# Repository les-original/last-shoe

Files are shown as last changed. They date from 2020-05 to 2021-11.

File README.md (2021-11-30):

# Last Shoe - The first bike shoe from LES ORIGINAL

### About 

#### FREE YOUR CLEATS FROM TYRANNY!
Performance cycling footwear in the comfort of your own home.

#### YOU DO SHOE.
The world's first additive-enabled bike shoes. Last is an open, modular and serviceable bike shoe platform made to adapt to any season, terrain or adventure.

#### RIGIDITY & FLEXION?
Designed for biking and hiking. The shoe is made to suit commuters, tourists and bikepackers who use the shoe for walking and biking. It's a firm pedaling platform with Metatarsal Articulation for walkability.

This project is a continuation of the _**N+ Platform**_, a project started by Marcs Wilkinson as a capstone project in **Product Design** at the _Wilson School of Design_, Kwantlen Polytechnic University.

**This model fits European size 45**

It's an additive enabled bike shoe designed to end all bike shoes. Designed for the creative cyclists, the project aspires to provide a shoe that is:

- Serviceable
- Modular
- Customizable

### Get Started & Stay Informed
[Les Original signup](https://www.marcsist.com/things/les-original/)

### See our other products
[Notion site](https://www.notion.so/lesoriginal/Products-c73553a3f9564c49b675799e58984206)


<br />This work is licensed under a <a rel="license" href="http://creativecommons.org/licenses/by-sa/4.0/">Creative Commons Attribution-ShareAlike 4.0 International License</a>.

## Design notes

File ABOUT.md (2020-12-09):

# Last bike shoe

## Challenges

1. Build adaptable bikepacking footwear with variable stiffness outsoles for riding and hiking
2. Most adventure cyclists ride through variety of climate and terrain, and buying purpose specific shoes adds up
3. With composite shanks, hardware and foams, cycling shoes are a multi-material disposal disaster

## Outcomes

1. A pleated rigid core that stops just shy of the metatarsal. Testing showed walkability close to a trail runner, while maintaining pedal stiffness comparable to a mountain bike shoe.
2. The N+ Platform - a quiver-killer of a shoe design that adapts to different types of riding, weather and adventures.
3. World's first additive-enabled, open source cycling shoe. Modular, serviceable, repairable with an open source design riders can adapt to their own needs. Semi-circular 3D printed TPU soles can be recycled into feedstock for new soles.

---

N+ is a bicycle shoe designed to provide a stiff pedaling platform while maintaining walkability off the bike. It's also an open-source design that's modular, serviceable and can be produced with readily available tools and techniques. It's a project exploring new consumer models of ownership and challenging expectations around the product life cycle.

N+ Platform was the final project of my Bachelor of Design - Product Design program in 2016 - read the  [Thesis Report](https://www.notion.so/Thesis-Report-795fb820494c4eefa807762894f369b8)

## Research

For this research project I was focused (okay not strictly focused as you will see...) on variable stiffness outsoles. The paradox I set out to solve — a walking/hiking shoe isn't ideal for biking, and a bike shoe is notoriously clumsy to walk in.

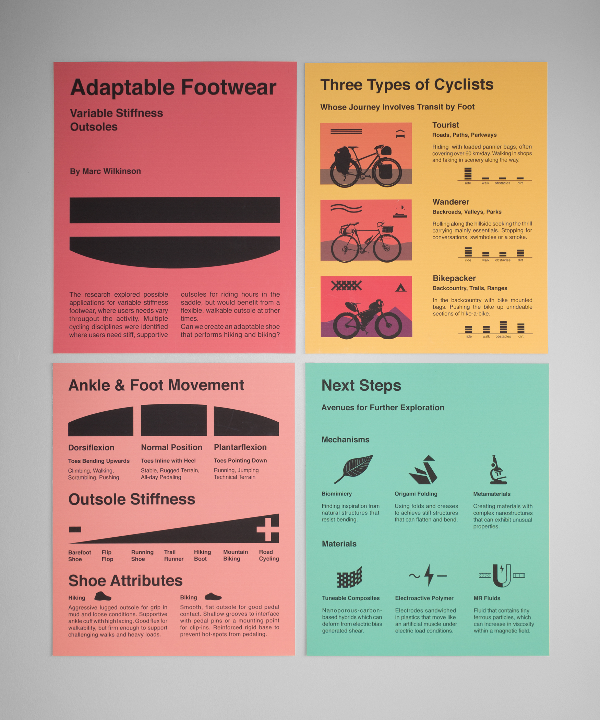
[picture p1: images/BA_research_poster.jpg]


Early research posters identifying challenge & opportunities



A mix of sketches at various fidelity

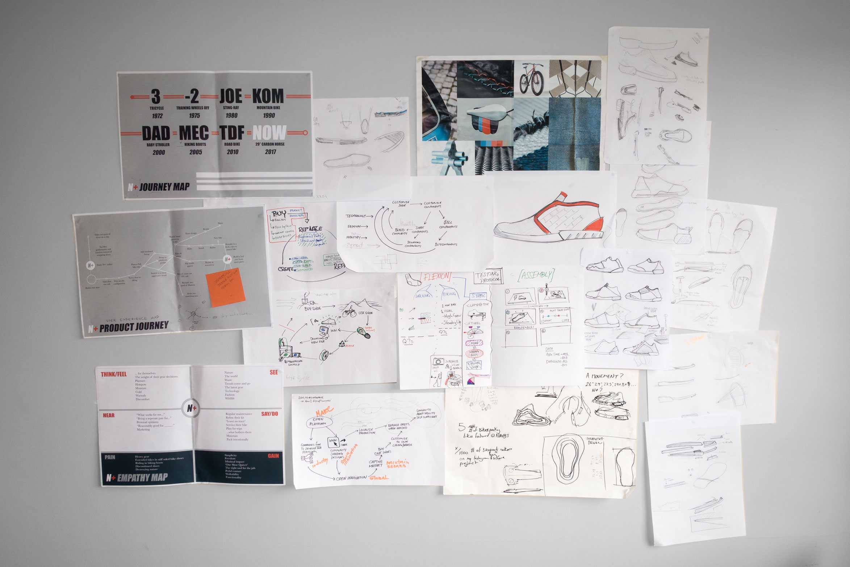
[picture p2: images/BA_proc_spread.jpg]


Assorted artefacts arranged on a wall

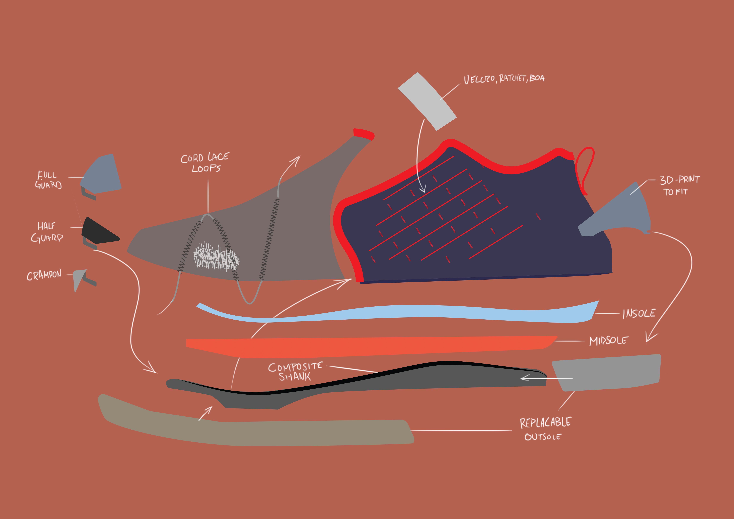
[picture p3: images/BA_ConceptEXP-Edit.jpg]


Exploded view of a concept (illustrator)

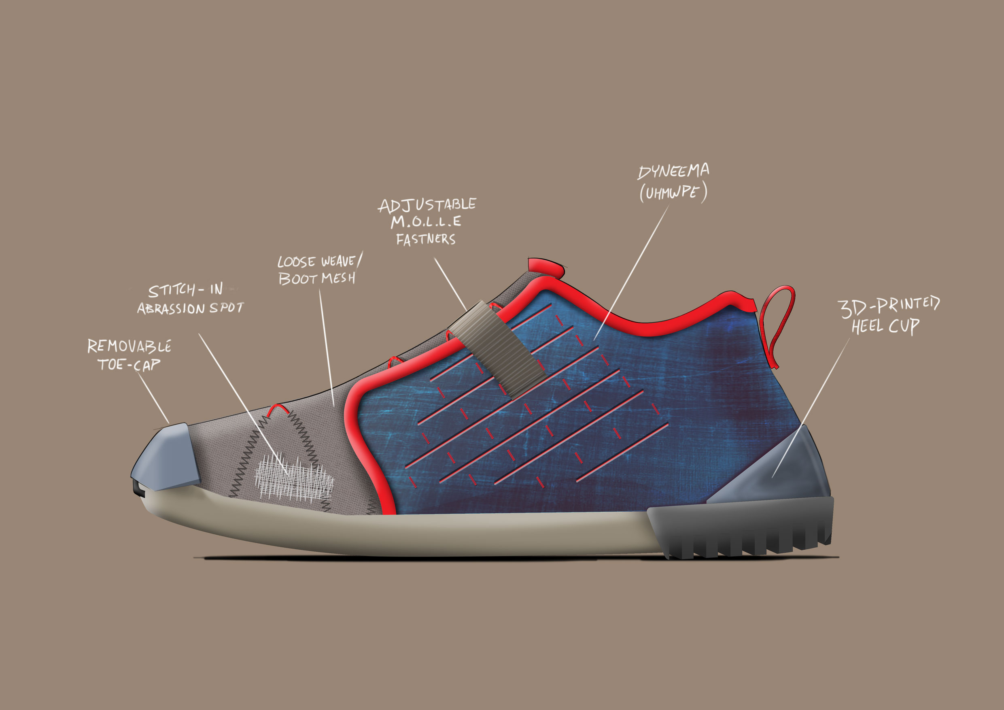
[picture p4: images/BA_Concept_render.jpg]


Rendered concept (photoshop)

## Design

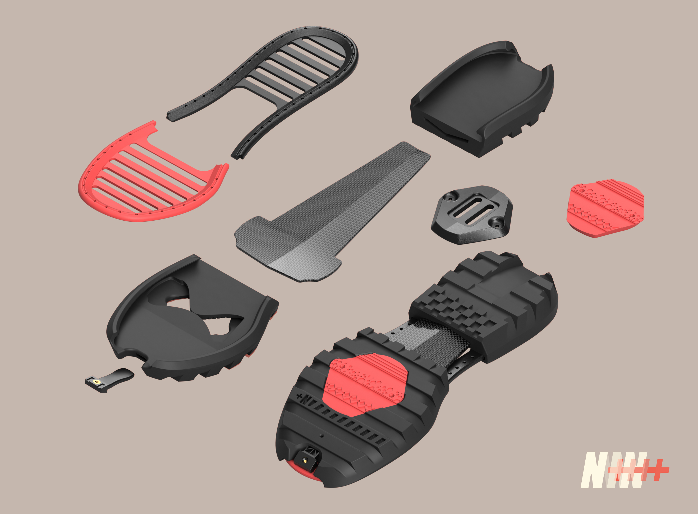
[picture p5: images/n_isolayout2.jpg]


Render in Fusion360 - one assembly surrounded by disassembled counterpart

### Modular Design

The shoe is designed as a modular system that allows riders to tweak and tune the shoe in the same way they would get a bike 'dialed' for a particular adventure.

- Easy to repair and disassemble
- replaceable outsole made without glue
- repairable and interchangeable textile
- tunable for different conditions, seasons, rides

As a bonus, non-traditional construction makes for a more sustainable extended product lifecycle. High-wear pieces like the outsole can be replaced when they're worn, and at different rates too — pedal wear happening faster than walking/heel wear. Textiles that tear or stink can be washed, repaired or replaced. The composite core, which will last centuries, fits a range of sizes and can be reused forever - leave it in your will!

### Additive-Enabled

Exploring the potential of digital manufacturing, I've used the term 'additive-enabled' because the composite core us made using a 3D printed mold and 3D printed threaded inserts to give shape to the core. The textile uppers are produced with good old fashioned textile technologies.

The frame (heel & toe), outsole (heel & toe), pedal inserts (platform & SPD) and toe-guard were all 3D printed.

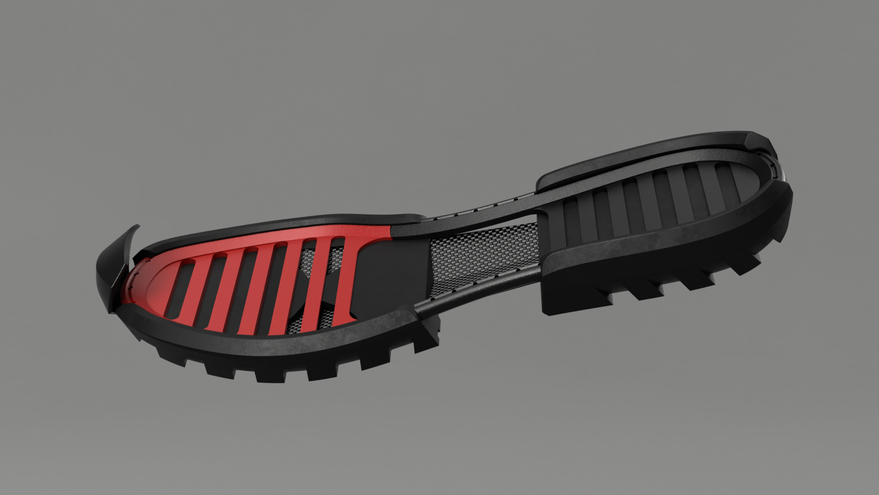
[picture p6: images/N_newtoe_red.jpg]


Render shown without textile uppers



Close-up of 3D printed TPU outsole

### Open-source Platform

So why a platform? What does that even mean? This project wouldn't have happened if it weren't for the RepRap project and proliferation of affordable 3D printing. I released the designs and project with an open source license because it would allow for a few interesting possibilities;

- People creating and sharing patterns and designs and components for free or profit
    - It would allow space for cottage makers to produce textile uppers, an interesting challenge and SKU
- Collaboration & competition
    - Imagine tire manufacturers adapt their existing tire tread catalog to fit the shoes
    - Imagine composite companies producing and selling cores
    - Imagine clothing and accessory brands can step into the shoe market with textile uppers and other parts
- Make nice bike shoes more accessible
    - People can make do with what they have available to hack together a decent shoe for themselves, that idea is pretty unthinkable for performance cycling shoes.
    - Eventually a market of used components (carbon cores) could exist to be combined with new replacement parts (fresh treads, textile uppers)

---

[les-original/last-shoe](https://github.com/les-original/last-shoe)



Assembled shoe, shoe components, DIY kit option

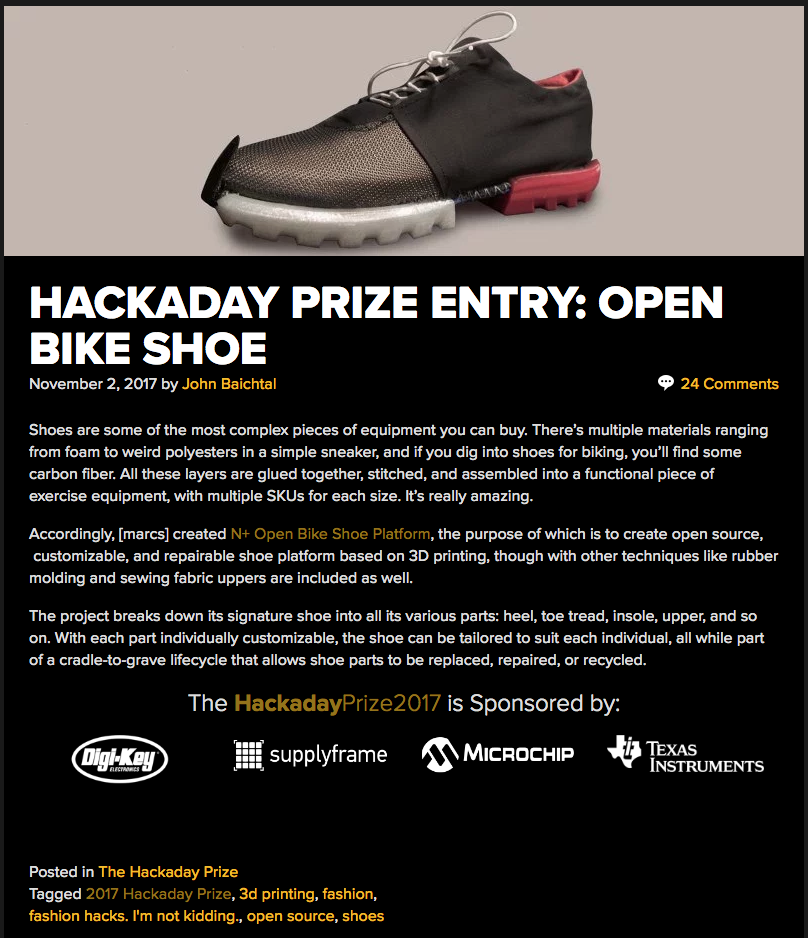
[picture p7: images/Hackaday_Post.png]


Top 20 finalist for **Hackaday**Prize2017 'Anything Goes' category

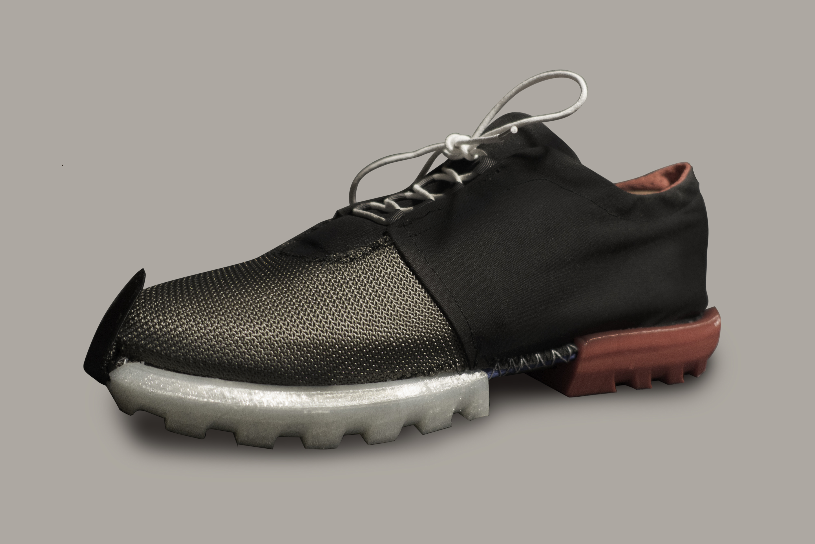
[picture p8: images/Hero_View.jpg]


Assembled shoe

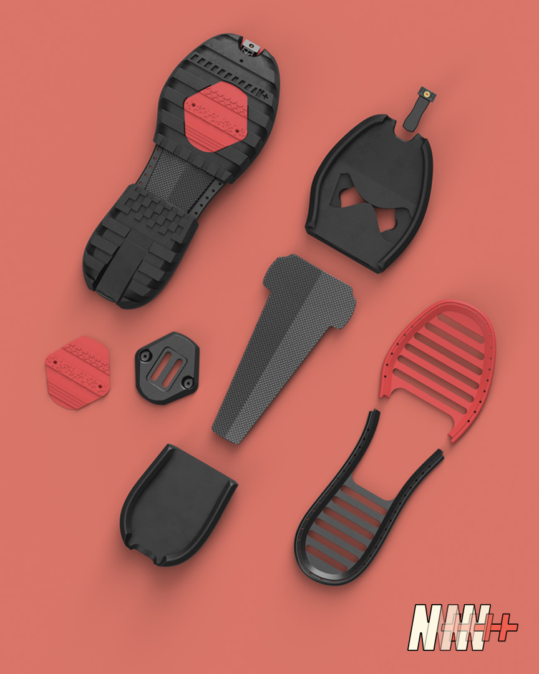
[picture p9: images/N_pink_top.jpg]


### Construction

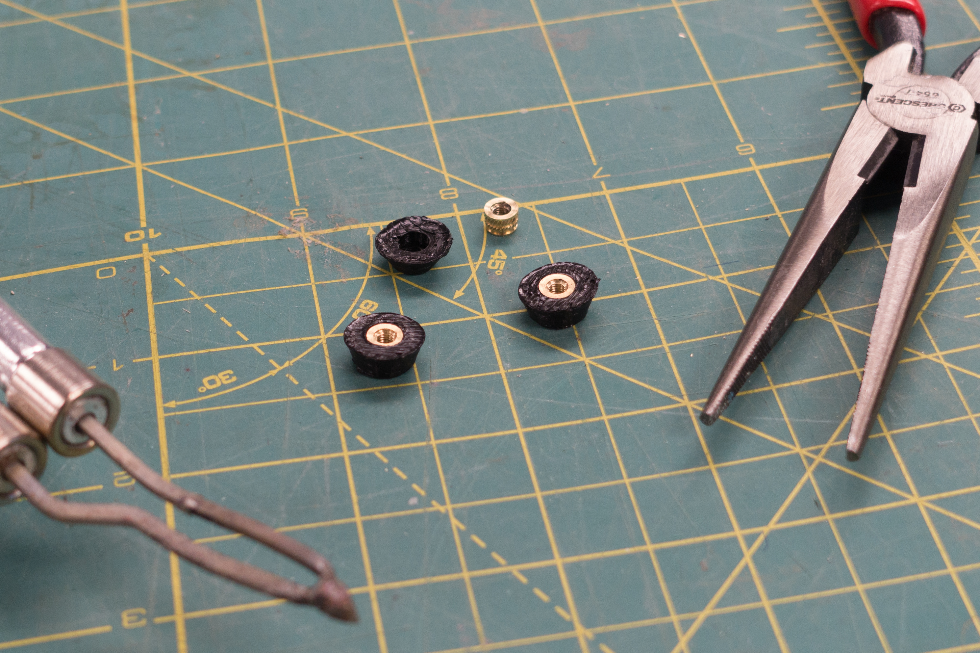
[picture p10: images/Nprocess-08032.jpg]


3D printed core inserts with heat-set threads



3D printed heel frame



Composite lay-up of the core

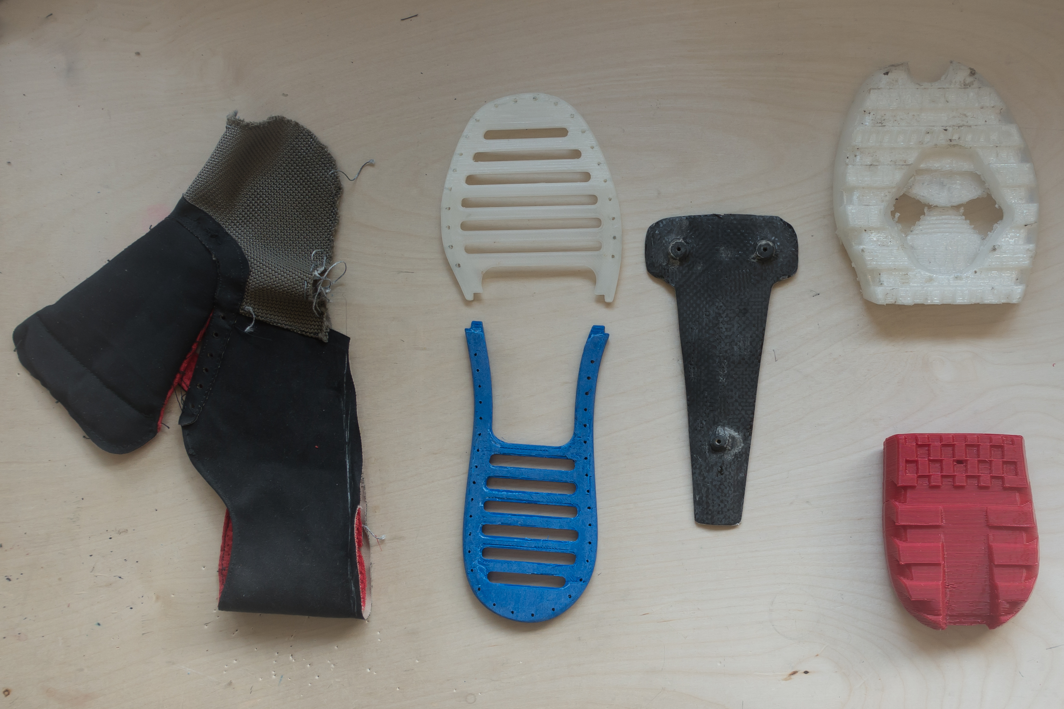
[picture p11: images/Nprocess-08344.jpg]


Textile uppers, frame, core, outsole



Printed mold, inserts, and CF/Flax matrix in a FoodSaver vacuum bag



Assembled after testing - with platform pedal insert

### Testing



Toe flexion - walking

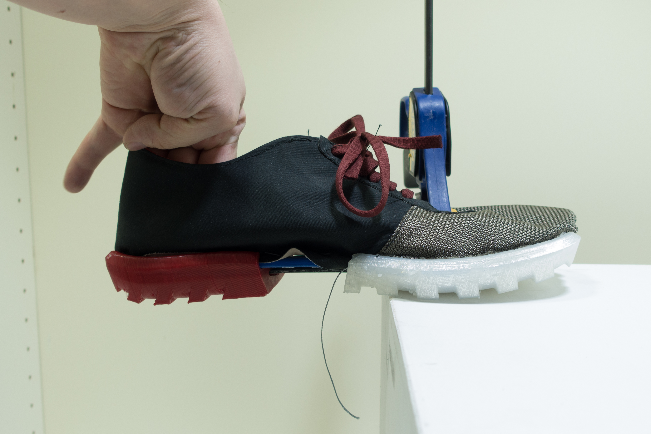
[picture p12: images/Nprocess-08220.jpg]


Toe flexion - pedalling

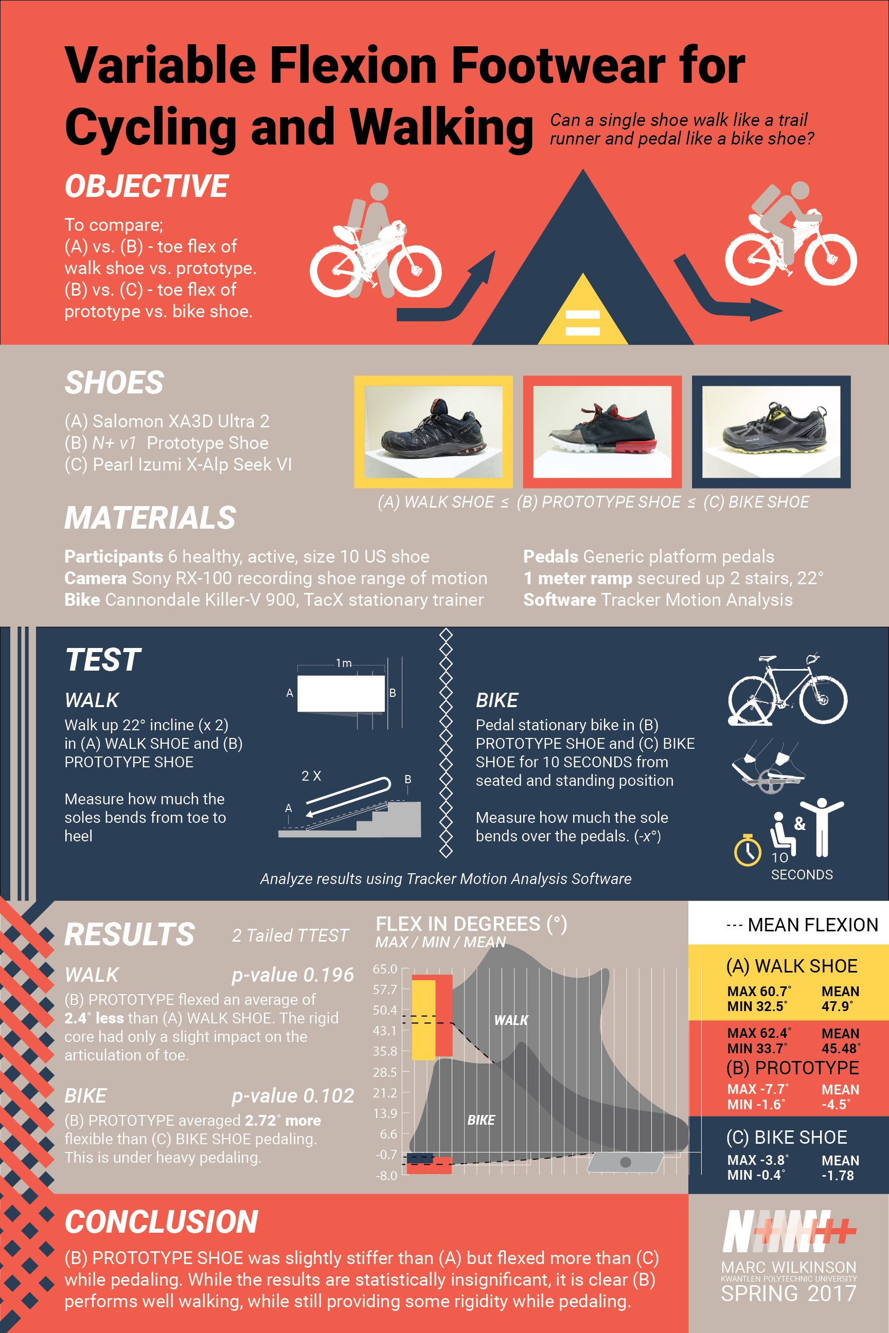
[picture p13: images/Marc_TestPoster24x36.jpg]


Research Testing Poster

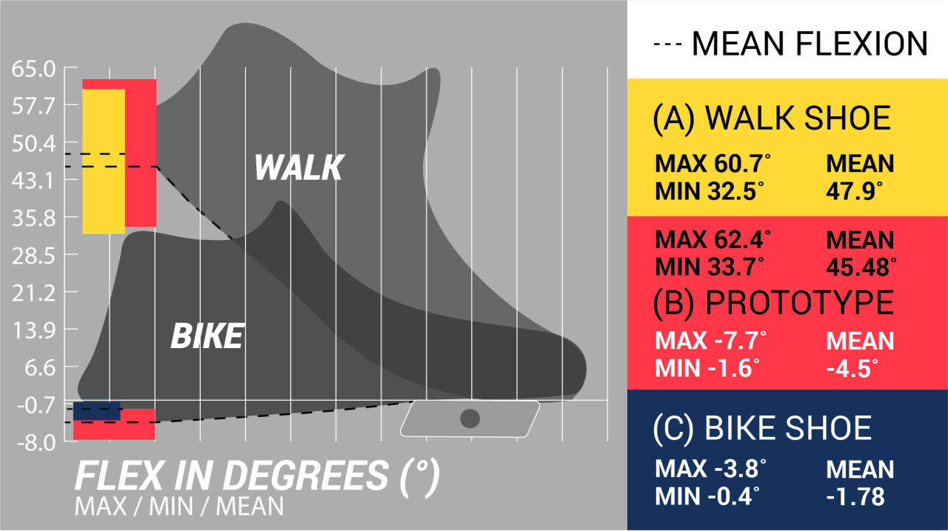
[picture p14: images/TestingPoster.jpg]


Testing Results show the prototype performed comparably to a cycling shoe and a trail runner



Three comparison shoes

# More Links

**I've shared some stuff on Instagram**

[#nplusplatform](https://www.instagram.com/explore/tags/nplusplatform/)

[@nplus.bike](https://www.instagram.com/nplus.bike/)

[Sign up](https://last.lesoriginal.com/n-plus-signup) to access more stuff related to this project

[GitHub repo](https://github.com/les-original/last-shoe)

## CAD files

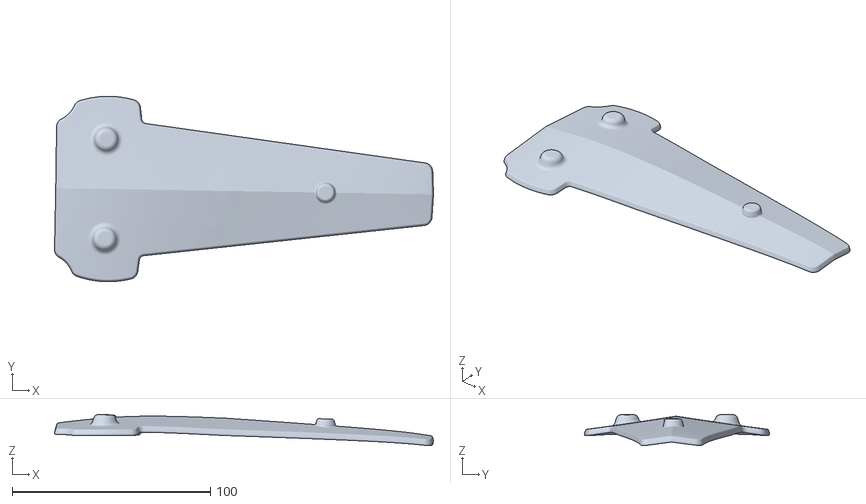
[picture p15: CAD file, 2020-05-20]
CORE/STL/last_core.stl
191.0 x 93.4 x 15.7

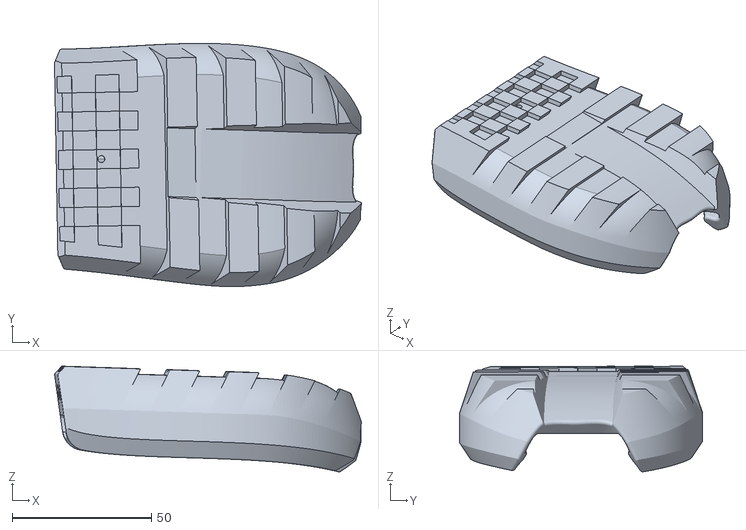
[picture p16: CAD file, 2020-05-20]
OUTSOLE/STL/Last_heel_US10.stl
110.2 x 87.3 x 38.0

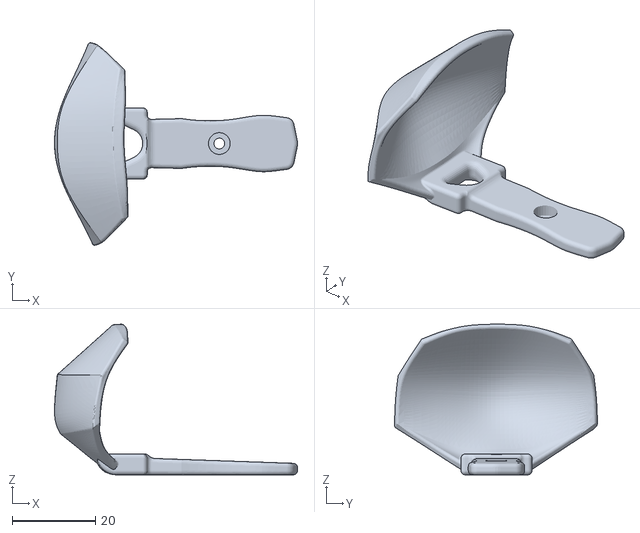
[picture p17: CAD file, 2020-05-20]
TOE GUARD/STL/Last_toeguard_v2.stl
58.5 x 48.7 x 36.2

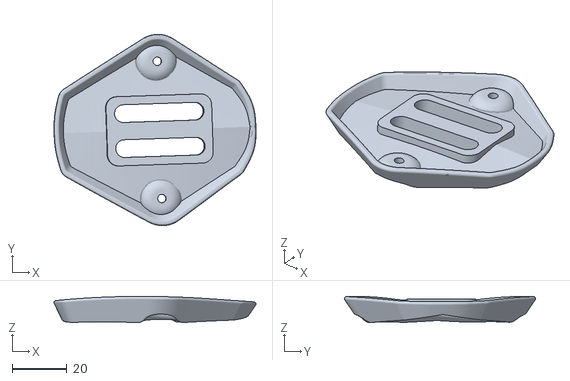
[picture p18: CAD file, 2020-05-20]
OUTSOLE/STL/Last_SPDinsert_US10.stl
73.5 x 69.7 x 9.56

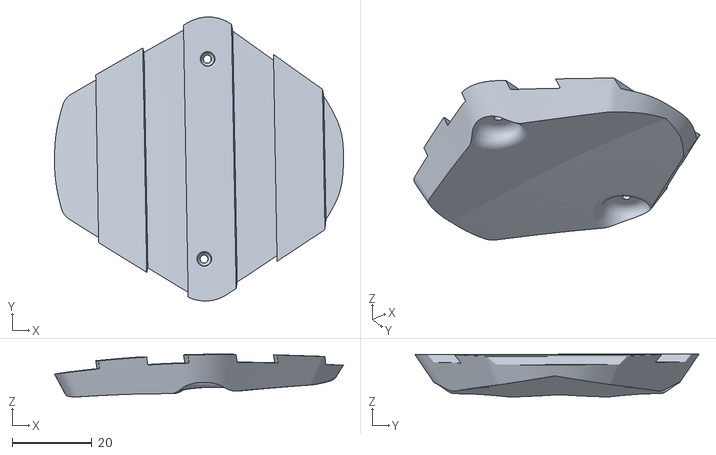
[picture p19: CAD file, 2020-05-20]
OUTSOLE/STL/Last_toeinsert_US10.stl
72.3 x 71.0 x 10.7

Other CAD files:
CORE/last_core.f3d
FRAME/Last_frame_toe_EU45.f3d
OUTSOLE/Last_SPDinsert_EU45.f3d
OUTSOLE/Last_toeinsert_EU45.f3d
TOE GUARD/Last_ToeGuard.f3d
TOE GUARD/Last_Toeguard Insert.f3d

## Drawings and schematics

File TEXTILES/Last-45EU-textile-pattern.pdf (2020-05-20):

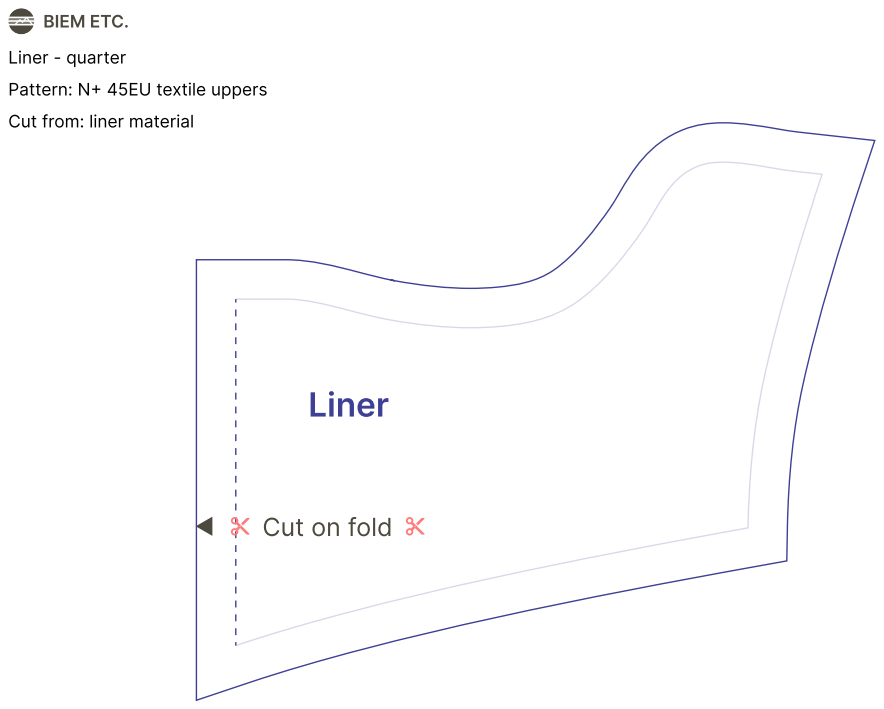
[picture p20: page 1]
Liner; BIEM ETC.; Liner - quarter

Pattern: N+ 45EU textile uppers

Cut from: liner material

Cut on fold

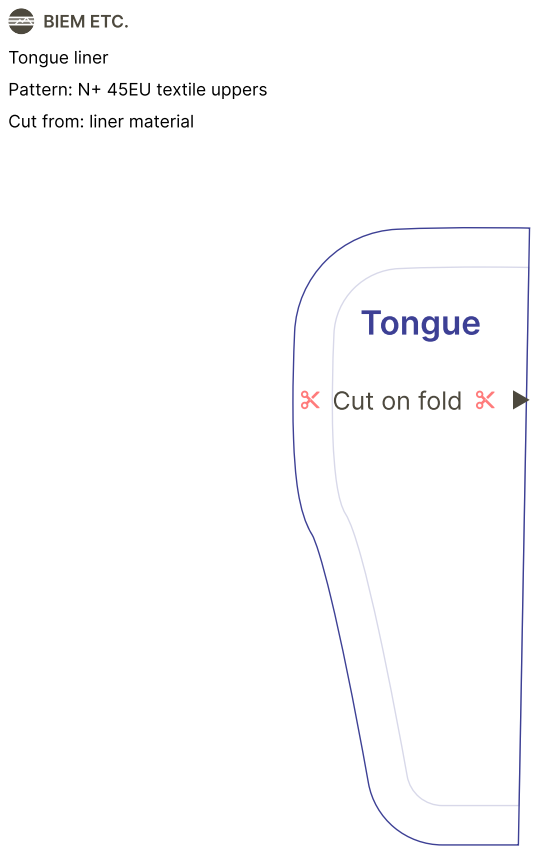
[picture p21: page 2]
Tongue; Tongue liner

Pattern: N+ 45EU textile uppers

Cut from: liner material

Cut on fold

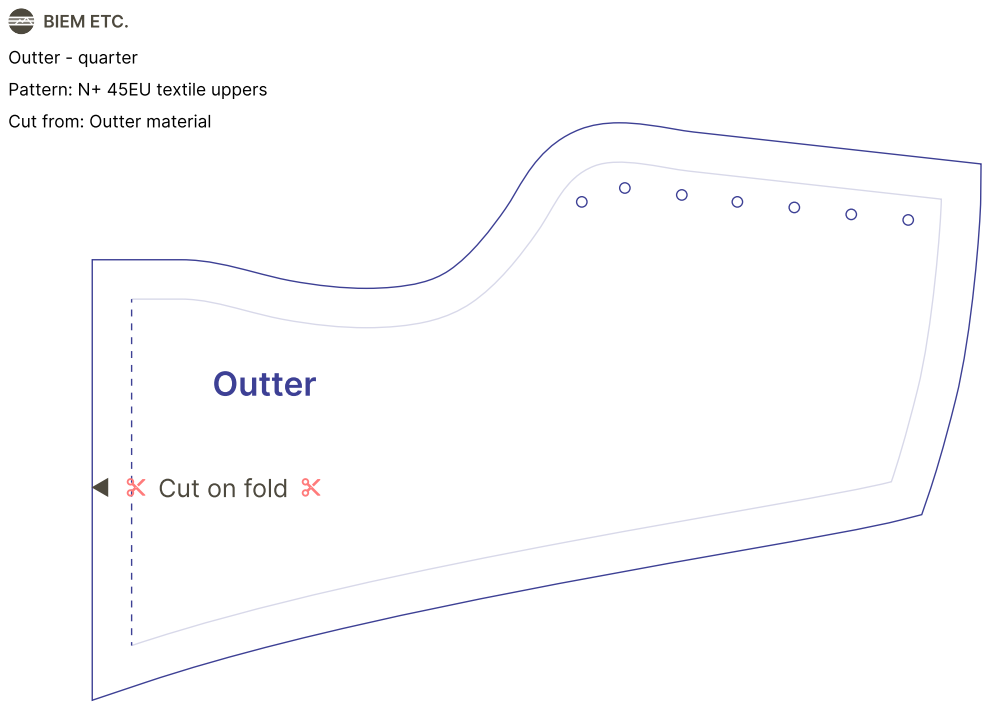
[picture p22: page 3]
Outter

Outter - quarter
Pattern: N+ 45EU textile uppers
Cut from: Outter material

Cut on fold

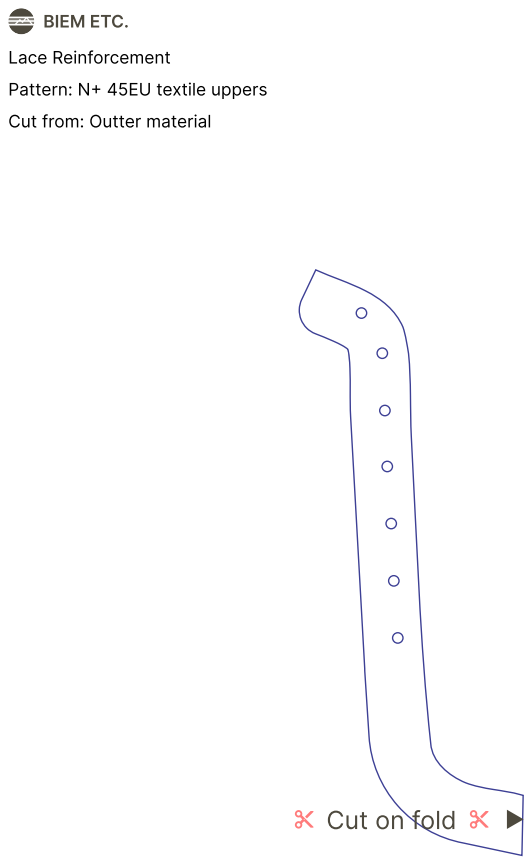
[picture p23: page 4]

Lace Reinforcement
Pattern: N+ 45EU textile uppers
Cut from: Outter material

Cut on fold

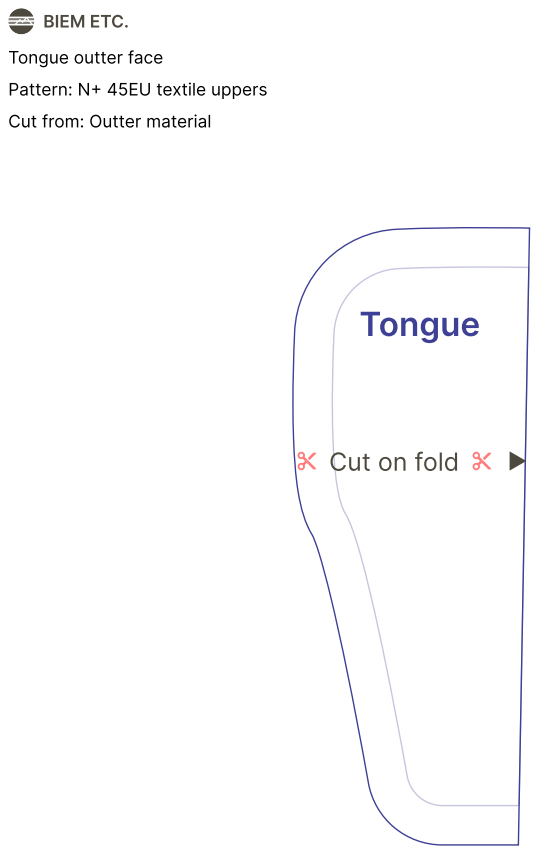
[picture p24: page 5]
Tongue

Tongue outter face
Pattern: N+ 45EU textile uppers
Cut from: Outter material

Cut on fold

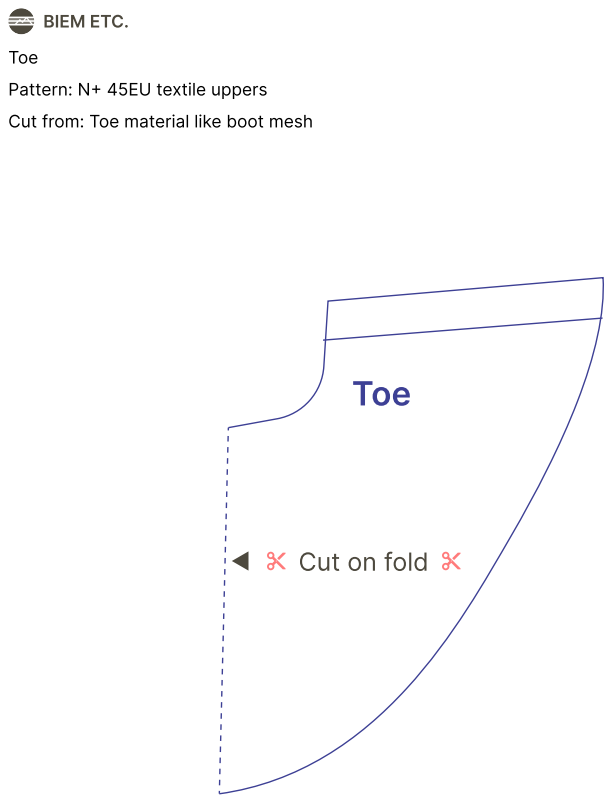
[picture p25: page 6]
Toe

Toe
Pattern: N+ 45EU textile uppers
Cut from: Toe material like boot mesh

Cut on fold

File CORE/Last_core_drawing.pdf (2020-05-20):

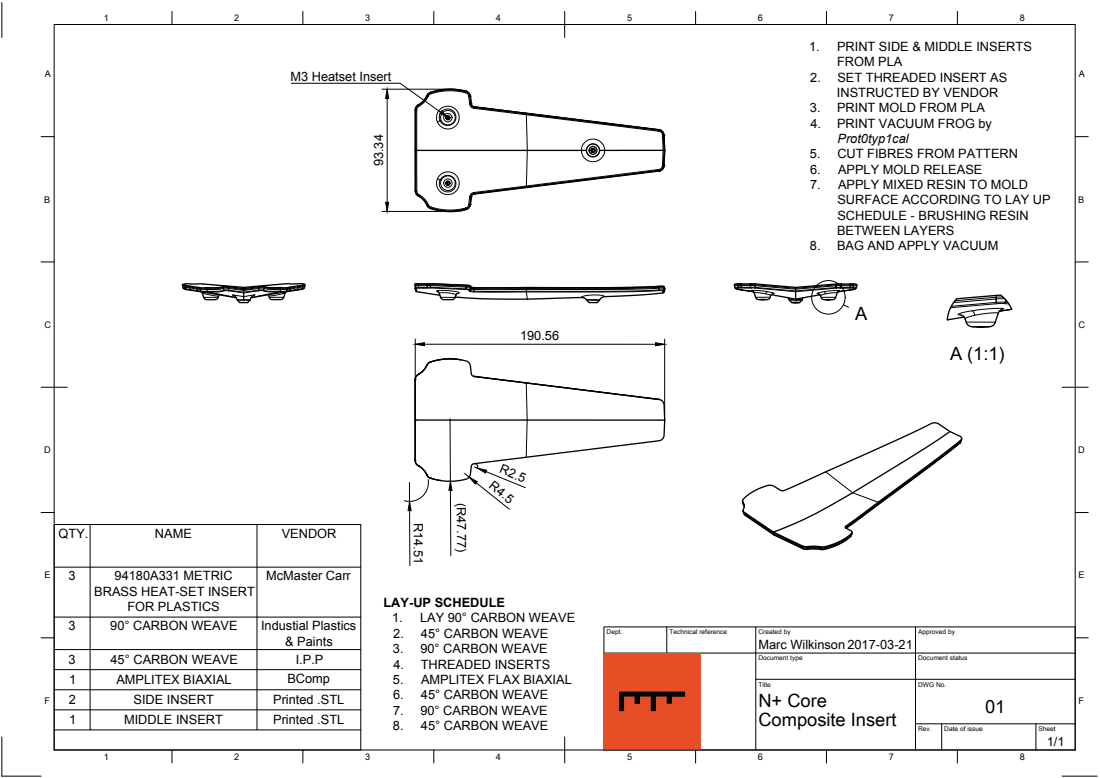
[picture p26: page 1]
M3 Heatset Insert

1. PRINT SIDE & MIDDLE INSERTS
FROM PLA
2. SET THREADED INSERT AS
INSTRUCTED BY VENDOR
3. PRINT MOLD FROM PLA
4. PRINT VACUUM FROG by
Prot0typ1cal
5. CUT FIBRES FROM PATTERN
6. APPLY MOLD RELEASE
7. APPLY MIXED RESIN TO MOLD
SURFACE ACCORDING TO LAY UP
SCHEDULE - BRUSHING RESIN
BETWEEN LAYERS

8. BAG AND APPLY VACUUM 93.34

QTY. | NAME | VENDOR

3 | 94180A331 METRIC BRASS HEAT-SET INSERT FOR PLASTICS | McMaster Carr

LAY-UP SCHEDULE
1. LAY 90° CARBON WEAVE
2. 45° CARBON WEAVE
3. 90° CARBON WEAVE
4. THREADED INSERTS
5. AMPLITEX FLAX BIAXIAL
6. 45° CARBON WEAVE
7. 90° CARBON WEAVE
8. 45° CARBON WEAVE

3 | 90° CARBON WEAVE | Industial Plastics & Paints

Dept. | Technical reference | Created by Marc Wilkinson 2017-03-21 | Approved by

3 | 45° CARBON WEAVE | I.P.P
1 | AMPLITEX BIAXIAL | BComp
2 | SIDE INSERT | Printed .STL
1 | MIDDLE INSERT | Printed .STL

Document type | Document status

Title N+ Core Composite Insert | DWG No. 01

Rev. | Date of issue | Sheet 1/1

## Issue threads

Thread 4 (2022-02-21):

Wooden core

marcsist, 2022-02-21:
# To Do

- [ ]  Fit into profile
- [ ]  Decide on material/process
- [ ]  Decide on fasteners
- [ ]  Figure out attachment points

# Summary

The new core should do everything better, easier. The design should be easy to produce (maybe not resin, maybe not 3D printed?) It will be variable stiffness, be made of woodlike a wood ski or skateboard

# Requirements

- Light
- Stiff
- Durable
- Fastens nicely to outsole
- Looks cool
- Producable

# Success metrics

- Cost to manufacture
- strength to weight
- Universality - one size fitting more is better!

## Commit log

2020-05-20 Nplus v1 files
    [Core.f3d, Nplus_SPDinsert_US10.f3d, Nplus_SPDinsert_US10.stl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]
2020-05-20 Added textile pattern pdf for 45eu
    [Core.f3d, Nplus_core.stl]
2020-05-20 Renamed from US10 to EU45
    Closer to a 10.5 anyways. Will use Euro sizing henceforth.
    [Nplus_SPDinsert_EU45.f3d, Nplus_frame_toe_EU45.f3d, Nplus_toeinsert_EU45.f3d]
2020-11-20 Name change
    N+ is now Last, the first bike shoe by LES ORIGINAL tourist equipment
    [Last_SPDinsert_EU45.f3d, Last_SPDinsert_US10.stl, Last_ToeGuard.f3d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]
